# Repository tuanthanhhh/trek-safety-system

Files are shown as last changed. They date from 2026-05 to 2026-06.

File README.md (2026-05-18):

# Outdoor Safety Tracker System
> A Personal Outdoor Safety Tracker designed for trekking and remote activities, featuring fall detection, GPS tracking, environmental sensing, and LoRa-based emergency communication for real-time user monitoring.

## 📌 Overview
This project implements a handheld embedded system that enhances user safety during outdoor activities such as trekking, hiking, or exploration in remote areas.

The system continuously monitors user status and environment, detects abnormal conditions (e.g., fall or unconsciousness), and transmits alerts to a central monitoring station via LoRa communication.

## 🎯 Key Features
- Fall detection
- Lora Communication
- GPS Tracking
- Environmental Monitoring
- Digital Compass
- Emergency SOS

## 🏗️ System Architecture
🚧 Work in progress

## 🔧 Hardware Components
🚧 Work in progress
## 🧠 Software Design

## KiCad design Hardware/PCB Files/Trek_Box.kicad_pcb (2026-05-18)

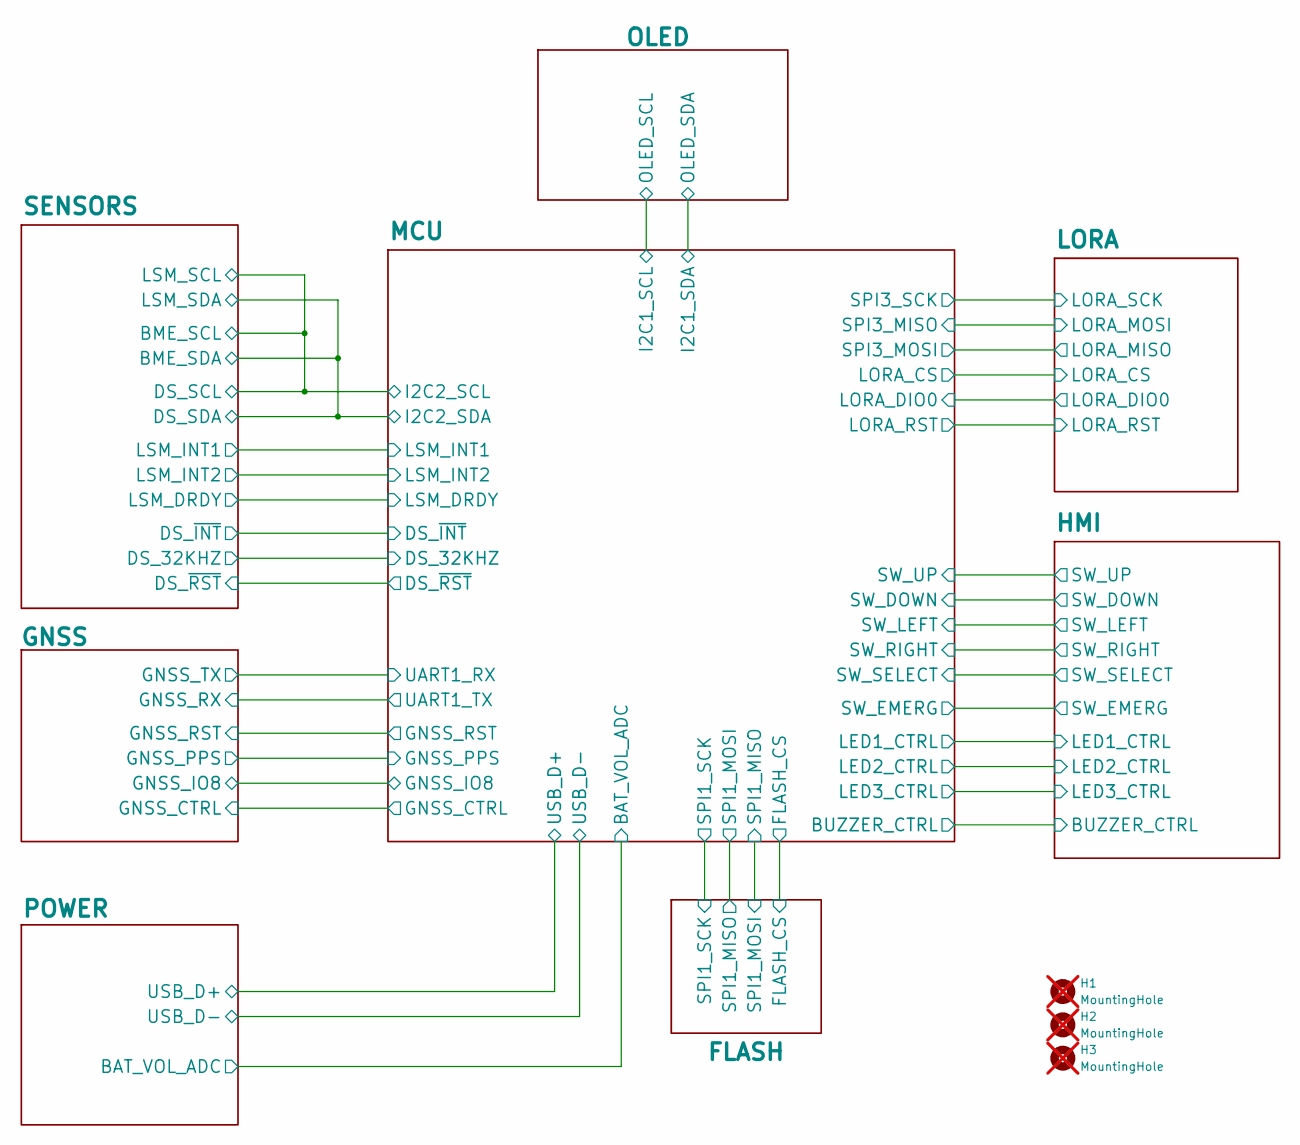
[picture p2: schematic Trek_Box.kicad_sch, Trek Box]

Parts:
H1, H2, H3: MountingHole; MountingHole_2.5mm; not fitted

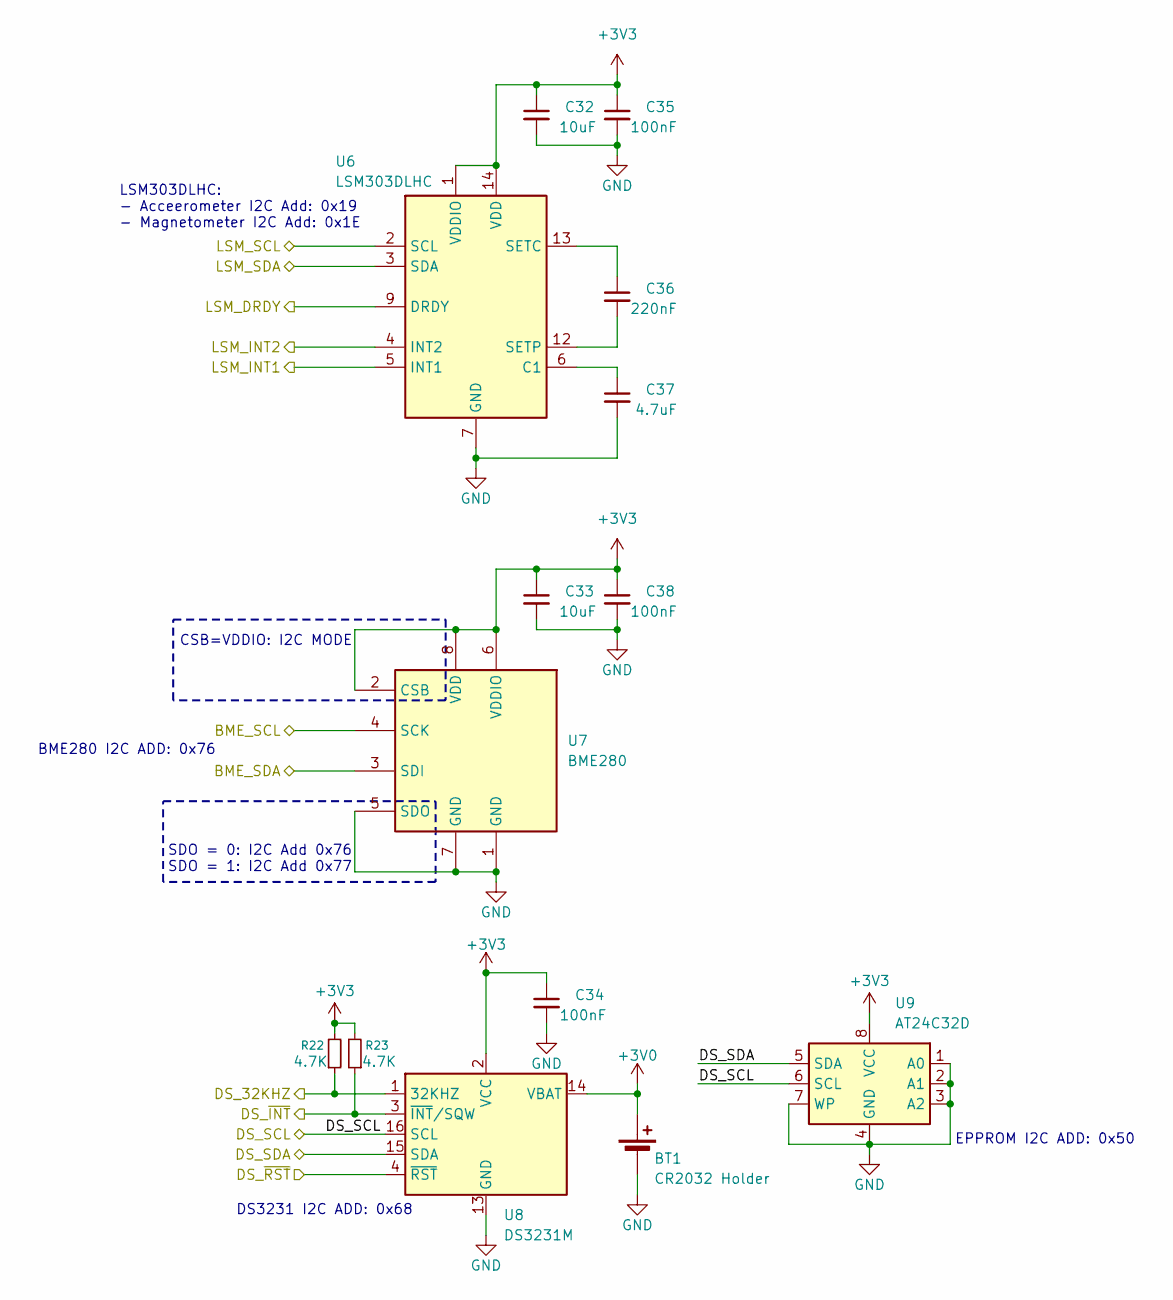
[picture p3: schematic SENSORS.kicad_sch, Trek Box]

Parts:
BT1: CR2032 Holder; BatteryHolder_Keystone_1060_1x2032
C32, C33: 10uF; C_0603_1608Metric; JLC C19702
C34, C35, C38: 100nF; C_0603_1608Metric; JLC C19702
C36: 220nF; C_0603_1608Metric; JLC C19702
C37: 4.7uF; C_0603_1608Metric; JLC C19702
R22, R23: 4.7K; R_0603_1608Metric
U6: LSM303DLHC; LGA-14_3x5mm_P0.8mm_LayoutBorder1x6y
U7: BME280; Bosch_LGA-8_2.5x2.5mm_P0.65mm_ClockwisePinNumbering
U8: DS3231M; SOIC-16W_7.5x10.3mm_P1.27mm
U9: AT24C32D; SOIC-8_3.9x4.9mm_P1.27mm

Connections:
+3V0: BT1.1 (+), U8.14 (VBAT); also elsewhere on the board
+3V3: C32.1, C33.1, C34.1, C35.1, C38.1, R22.2, R23.2, U6.1 (VDDIO), U6.14 (VDD), U7.2 (CSB), U7.6 (VDDIO), U7.8 (VDD), U8.2 (VCC), U9.8 (VCC); also elsewhere on the board
/MCU/DS_32KHZ: R22.1, U8.1 (32KHZ); also elsewhere on the board
/MCU/DS_~INT: R23.1, U8.3 (~INT/SQW); also elsewhere on the board
/MCU/DS_~RST: U8.4 (~RST); also elsewhere on the board
/MCU/I2C2_SCL: U6.2 (SCL), U7.4 (SCK), U8.16 (SCL), U9.6 (SCL); also elsewhere on the board
/MCU/I2C2_SDA: U6.3 (SDA), U7.3 (SDI), U8.15 (SDA), U9.5 (SDA); also elsewhere on the board
/MCU/LSM_DRDY: U6.9 (DRDY); also elsewhere on the board
/MCU/LSM_INT1: U6.5 (INT1); also elsewhere on the board
/MCU/LSM_INT2: U6.4 (INT2); also elsewhere on the board
GND: BT1.2 (-), C32.2, C33.2, C34.2, C35.2, C37.2, C38.2, U6.7 (GND), U6.10 (GND), U6.11 (GND), U7.1 (GND), U7.5 (SDO), U7.7 (GND), U8.5 (GND), U8.6 (GND), U8.7 (GND), U8.8 (GND), U8.9 (GND), U8.10 (GND), U8.11 (GND), U8.12 (GND), U8.13 (GND), U9.1 (A0), U9.2 (A1), U9.3 (A2), U9.4 (GND), U9.7 (WP); also elsewhere on the board
unnamed: C37.1, U6.6 (C1)
unnamed: C36.1, U6.13 (SETC)
unnamed: C36.2, U6.12 (SETP)

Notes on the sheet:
BME280 I2C ADD: 0x76
LSM303DLHC: - Acceerometer I2C Add: 0x19 - Magnetometer I2C Add: 0x1E
DS3231 I2C ADD: 0x68
SDO = 0: I2C Add 0x76 SDO = 1: I2C Add 0x77
CSB=VDDIO: I2C MODE
EPPROM I2C ADD: 0x50

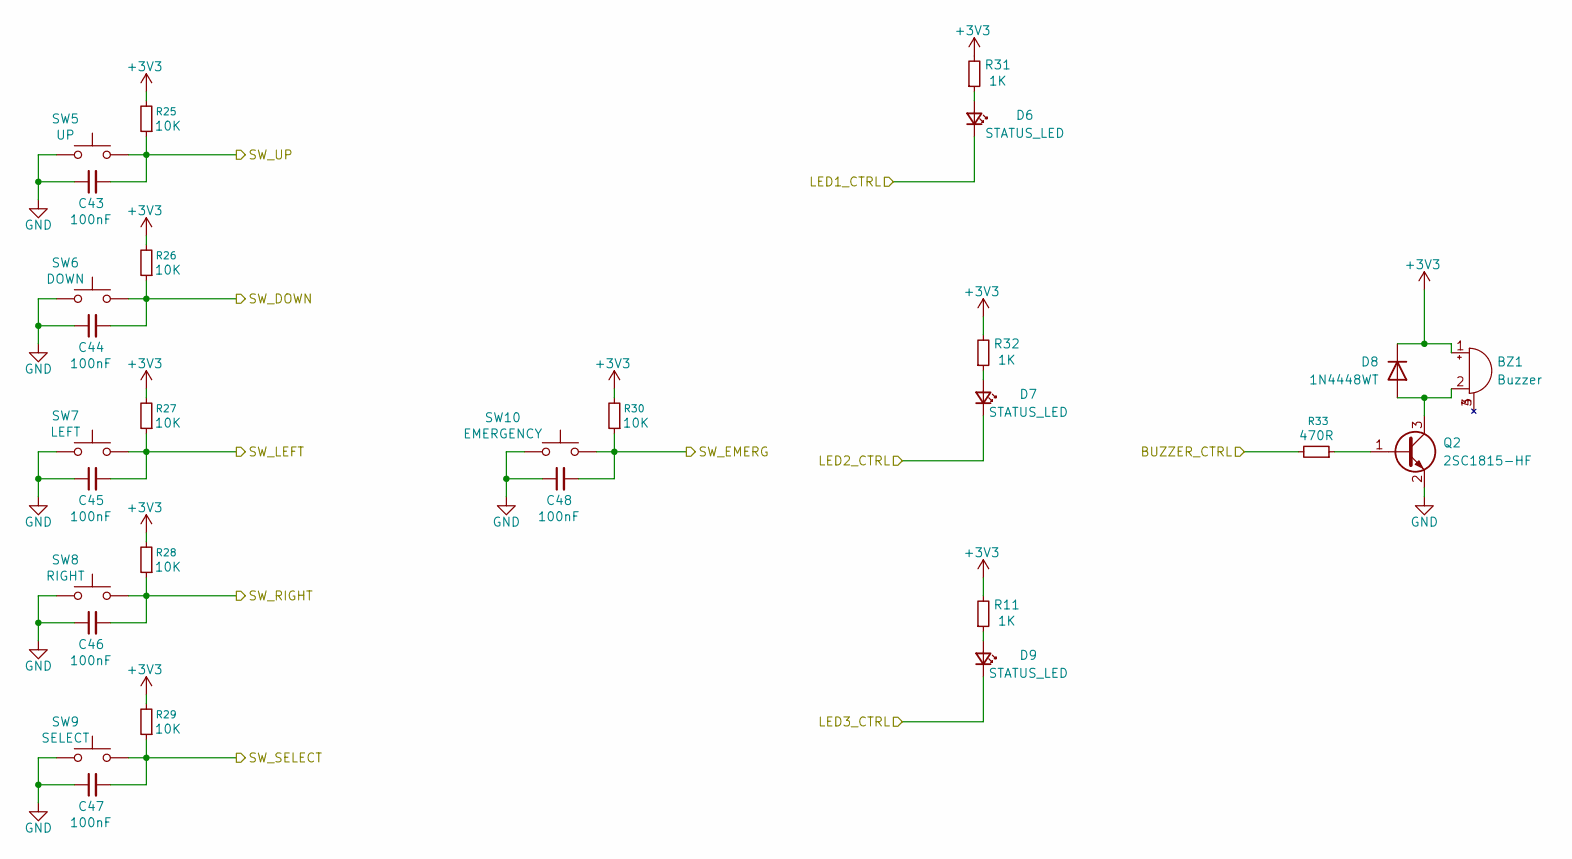
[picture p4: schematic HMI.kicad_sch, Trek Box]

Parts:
BZ1: Buzzer; Buzzer_8530
C43, C44, C45, C46, C47, C48: 100nF; C_0603_1608Metric
D6, D7, D9: STATUS_LED; LED_0603_1608Metric; JLC C2286
D8: 1N4448WT; D_SOD-523
Q2: 2SC1815-HF; SOT-23
R11, R31, R32: 1K; R_0603_1608Metric
R25, R26, R27, R28, R29, R30: 10K; R_0603_1608Metric
R33: 470R; R_0603_1608Metric
SW5: UP; SW_SPST_PTS647_Sx38
SW6: DOWN; SW_SPST_PTS647_Sx38
SW7: LEFT; SW_SPST_PTS647_Sx38
SW8: RIGHT; SW_SPST_PTS647_Sx38
SW9: SELECT; SW_SPST_PTS647_Sx38
SW10: EMERGENCY; SW_Tactile_SPST_Angled_PTS645Vx58-2LFS

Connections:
+3V3: BZ1.1 (+), D8.1 (K), R11.2, R25.2, R26.2, R27.2, R28.2, R29.2, R30.2, R31.2, R32.2; also elsewhere on the board
/HMI/BUZZER_CTRL: R33.2; also elsewhere on the board
/HMI/LED1_CTRL: D6.1 (K); also elsewhere on the board
/HMI/LED2_CTRL: D7.1 (K); also elsewhere on the board
/HMI/LED3_CTRL: D9.1 (K); also elsewhere on the board
/HMI/SW_DOWN: C44.2, R26.1, SW6.1; also elsewhere on the board
/HMI/SW_EMERG: C48.2, R30.1, SW10.1; also elsewhere on the board
/HMI/SW_LEFT: C45.2, R27.1, SW7.1; also elsewhere on the board
/HMI/SW_RIGHT: C46.2, R28.1, SW8.1; also elsewhere on the board
/HMI/SW_SELECT: C47.2, R29.1, SW9.1; also elsewhere on the board
/HMI/SW_UP: C43.2, R25.1, SW5.1; also elsewhere on the board
GND: C43.1, C44.1, C45.1, C46.1, C47.1, C48.1, Q2.2 (E), SW5.2, SW6.2, SW7.2, SW8.2, SW9.2, SW10.2; also elsewhere on the board
unnamed: BZ1.2 (-), D8.2 (A), Q2.3 (C)
unnamed: D6.2 (A), R31.1
unnamed: D7.2 (A), R32.1
unnamed: D9.2 (A), R11.1
unnamed: Q2.1 (B), R33.1

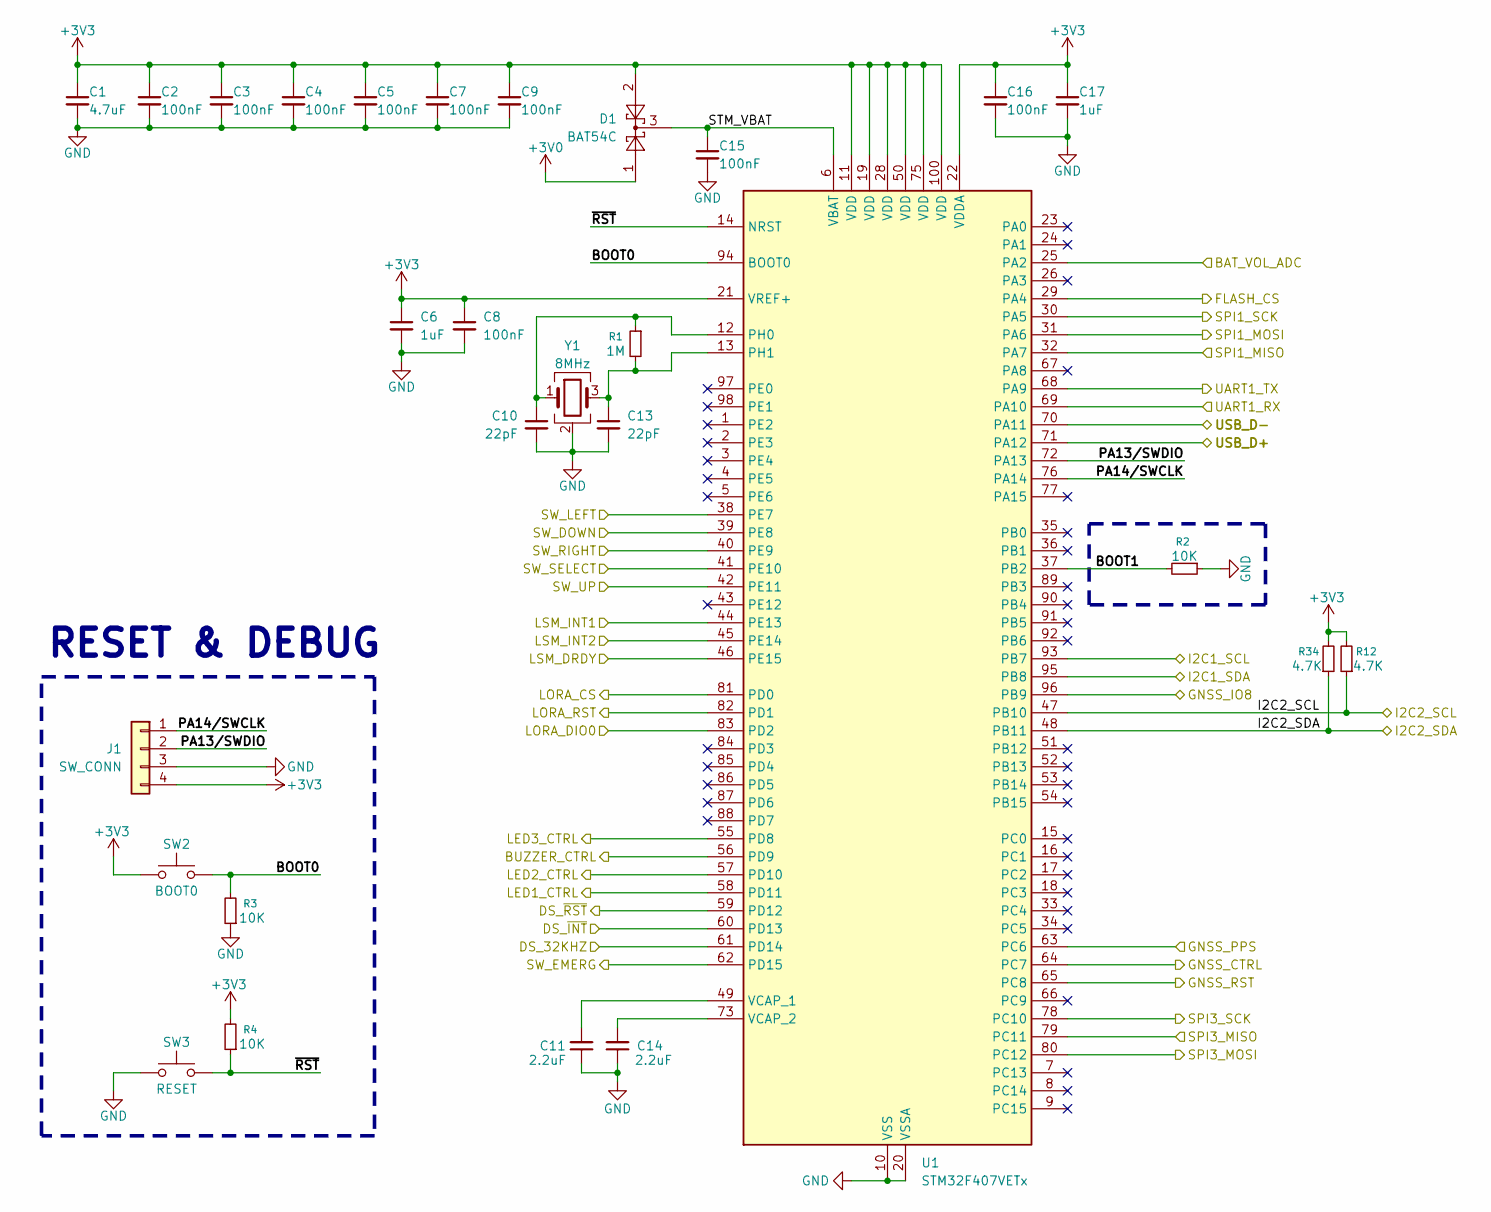
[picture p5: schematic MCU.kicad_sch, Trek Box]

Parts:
C1: 4.7uF; C_0603_1608Metric
C2, C3, C4, C5, C7, C8, C9, C15, C16: 100nF; C_0603_1608Metric
C6, C17: 1uF; C_0603_1608Metric
C10, C13: 22pF; C_0603_1608Metric
C11, C14: 2.2uF; C_0603_1608Metric
D1: BAT54C; SOT-23
J1: SW_CONN; PinHeader_1x04_P2.54mm_Vertical
R1: 1M; R_0603_1608Metric
R2, R3, R4: 10K; R_0603_1608Metric
R12, R34: 4.7K; R_0603_1608Metric
SW2: BOOT0; SW_SPST_PTS647_Sx38
SW3: RESET; SW_SPST_PTS647_Sx38
U1: STM32F407VETx; LQFP-100_14x14mm_P0.5mm
Y1: 8MHz; Crystal_SMD_3225-4Pin_3.2x2.5mm

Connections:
+3V0: D1.1; also elsewhere on the board
+3V3: C1.1, C2.1, C3.1, C4.1, C5.1, C6.1, C7.1, C8.1, C9.1, C16.1, C17.1, D1.2, J1.4, R4.2, R12.2, R34.2, SW2.2, U1.11 (VDD), U1.19 (VDD), U1.21 (VREF+), U1.22 (VDDA), U1.28 (VDD), U1.50 (VDD), U1.75 (VDD), U1.100 (VDD); also elsewhere on the board
/FLASH/FLASH_CS: U1.29 (PA4); also elsewhere on the board
/FLASH/SPI1_MISO: U1.31 (PA6); also elsewhere on the board
/FLASH/SPI1_MOSI: U1.32 (PA7); also elsewhere on the board
/FLASH/SPI1_SCK: U1.30 (PA5); also elsewhere on the board
/GNSS/GNSS_CTRL: U1.64 (PC7); also elsewhere on the board
/GNSS/GNSS_IO8: U1.96 (PB9); also elsewhere on the board
/GNSS/GNSS_PPS: U1.63 (PC6); also elsewhere on the board
/GNSS/GNSS_RST: U1.65 (PC8); also elsewhere on the board
/GNSS/GNSS_RX: U1.68 (PA9); also elsewhere on the board
/GNSS/GNSS_TX: U1.69 (PA10); also elsewhere on the board
/HMI/BUZZER_CTRL: U1.56 (PD9); also elsewhere on the board
/HMI/LED1_CTRL: U1.58 (PD11); also elsewhere on the board
/HMI/LED2_CTRL: U1.57 (PD10); also elsewhere on the board
/HMI/LED3_CTRL: U1.55 (PD8); also elsewhere on the board
/HMI/SW_DOWN: U1.39 (PE8); also elsewhere on the board
/HMI/SW_EMERG: U1.62 (PD15); also elsewhere on the board
/HMI/SW_LEFT: U1.38 (PE7); also elsewhere on the board
/HMI/SW_RIGHT: U1.40 (PE9); also elsewhere on the board
/HMI/SW_SELECT: U1.41 (PE10); also elsewhere on the board
/HMI/SW_UP: U1.42 (PE11); also elsewhere on the board
/LORA/LORA_CS: U1.81 (PD0); also elsewhere on the board
/LORA/LORA_INT: U1.83 (PD2); also elsewhere on the board
/LORA/LORA_MISO: U1.80 (PC12); also elsewhere on the board
/LORA/LORA_MOSI: U1.79 (PC11); also elsewhere on the board
/LORA/LORA_RST: U1.82 (PD1); also elsewhere on the board
/LORA/LORA_SCK: U1.78 (PC10); also elsewhere on the board
/MCU/BAT_VOL_ADC: U1.25 (PA2); also elsewhere on the board
/MCU/BOOT0: R3.2, SW2.1, U1.94 (BOOT0)
/MCU/BOOT1: R2.2, U1.37 (PB2)
/MCU/DS_32KHZ: U1.61 (PD14); also elsewhere on the board
/MCU/DS_~INT: U1.60 (PD13); also elsewhere on the board
/MCU/DS_~RST: U1.59 (PD12); also elsewhere on the board
/MCU/I2C1_SCL: U1.93 (PB7); also elsewhere on the board
/MCU/I2C1_SDA: U1.95 (PB8); also elsewhere on the board
/MCU/I2C2_SCL: R12.1, U1.47 (PB10); also elsewhere on the board
/MCU/I2C2_SDA: R34.1, U1.48 (PB11); also elsewhere on the board
/MCU/LSM_DRDY: U1.46 (PE15); also elsewhere on the board
/MCU/LSM_INT1: U1.44 (PE13); also elsewhere on the board
/MCU/LSM_INT2: U1.45 (PE14); also elsewhere on the board
/MCU/PA13/SWDIO: J1.2, U1.72 (PA13)
/MCU/PA14/SWCLK: J1.1, U1.76 (PA14)
/MCU/STM_VBAT: C15.1, D1.3, U1.6 (VBAT)
/MCU/~RST: R4.1, SW3.1, U1.14 (NRST)
/POWER/USB_D+: U1.71 (PA12); also elsewhere on the board
/POWER/USB_D-: U1.70 (PA11); also elsewhere on the board
GND: C1.2, C2.2, C3.2, C4.2, C5.2, C6.2, C7.2, C8.2, C9.2, C10.2, C11.1, C13.2, C14.1, C15.2, C16.2, C17.2, J1.3, R2.1, R3.1, SW3.2, U1.10 (VSS), U1.20 (VSSA), U1.27 (VSS), U1.74 (VSS), U1.99 (VSS), Y1.2 (G), Y1.4 (G); also elsewhere on the board
unnamed: C10.1, R1.1, U1.12 (PH0), Y1.1
unnamed: C13.1, R1.2, U1.13 (PH1), Y1.3
unnamed: C11.2, U1.49 (VCAP_1)
unnamed: C14.2, U1.73 (VCAP_2)

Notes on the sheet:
RESET & DEBUG

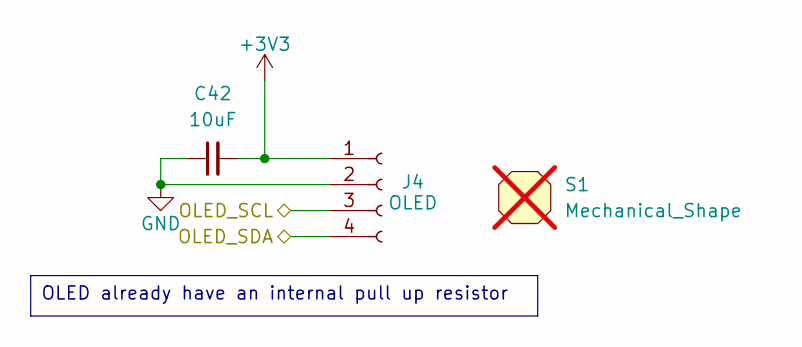
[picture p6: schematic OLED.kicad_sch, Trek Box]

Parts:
C42: 10uF; C_0603_1608Metric
J4: OLED; PinHeader_1x04_P2.54mm_Vertical
S1: Mechanical_Shape; OLED_1inch3; not fitted

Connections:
+3V3: C42.2, J4.1; also elsewhere on the board
/MCU/I2C1_SCL: J4.3; also elsewhere on the board
/MCU/I2C1_SDA: J4.4; also elsewhere on the board
GND: C42.1, J4.2; also elsewhere on the board

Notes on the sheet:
OLED already have an internal pull up resistor

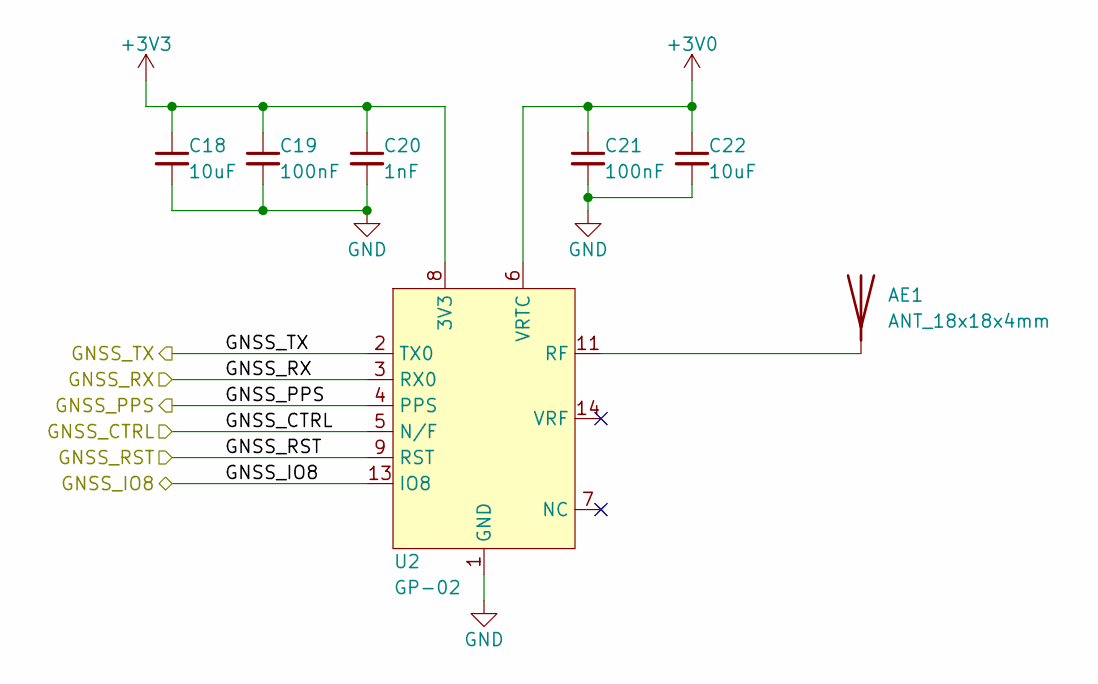
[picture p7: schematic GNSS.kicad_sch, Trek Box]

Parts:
AE1: ANT_18x18x4mm; PATH_ANT_18x18x4mm
C18, C22: 10uF; C_0603_1608Metric
C19, C21: 100nF; C_0603_1608Metric
C20: 1nF; C_0603_1608Metric
U2: GP-02; GP-02_FULL_PAD

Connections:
+3V0: C21.1, C22.1, U2.6 (VRTC); also elsewhere on the board
+3V3: C18.1, C19.1, C20.1, U2.8 (3V3); also elsewhere on the board
/GNSS/GNSS_CTRL: U2.5 (N/F); also elsewhere on the board
/GNSS/GNSS_IO8: U2.13 (IO8); also elsewhere on the board
/GNSS/GNSS_PPS: U2.4 (PPS); also elsewhere on the board
/GNSS/GNSS_RST: U2.9 (RST); also elsewhere on the board
/GNSS/GNSS_RX: U2.3 (RX0); also elsewhere on the board
/GNSS/GNSS_TX: U2.2 (TX0); also elsewhere on the board
GND: C18.2, C19.2, C20.2, C21.2, C22.2, U2.1 (GND), U2.10 (GND), U2.12 (GND); also elsewhere on the board
unnamed: AE1.1 (A_1), U2.11 (RF)

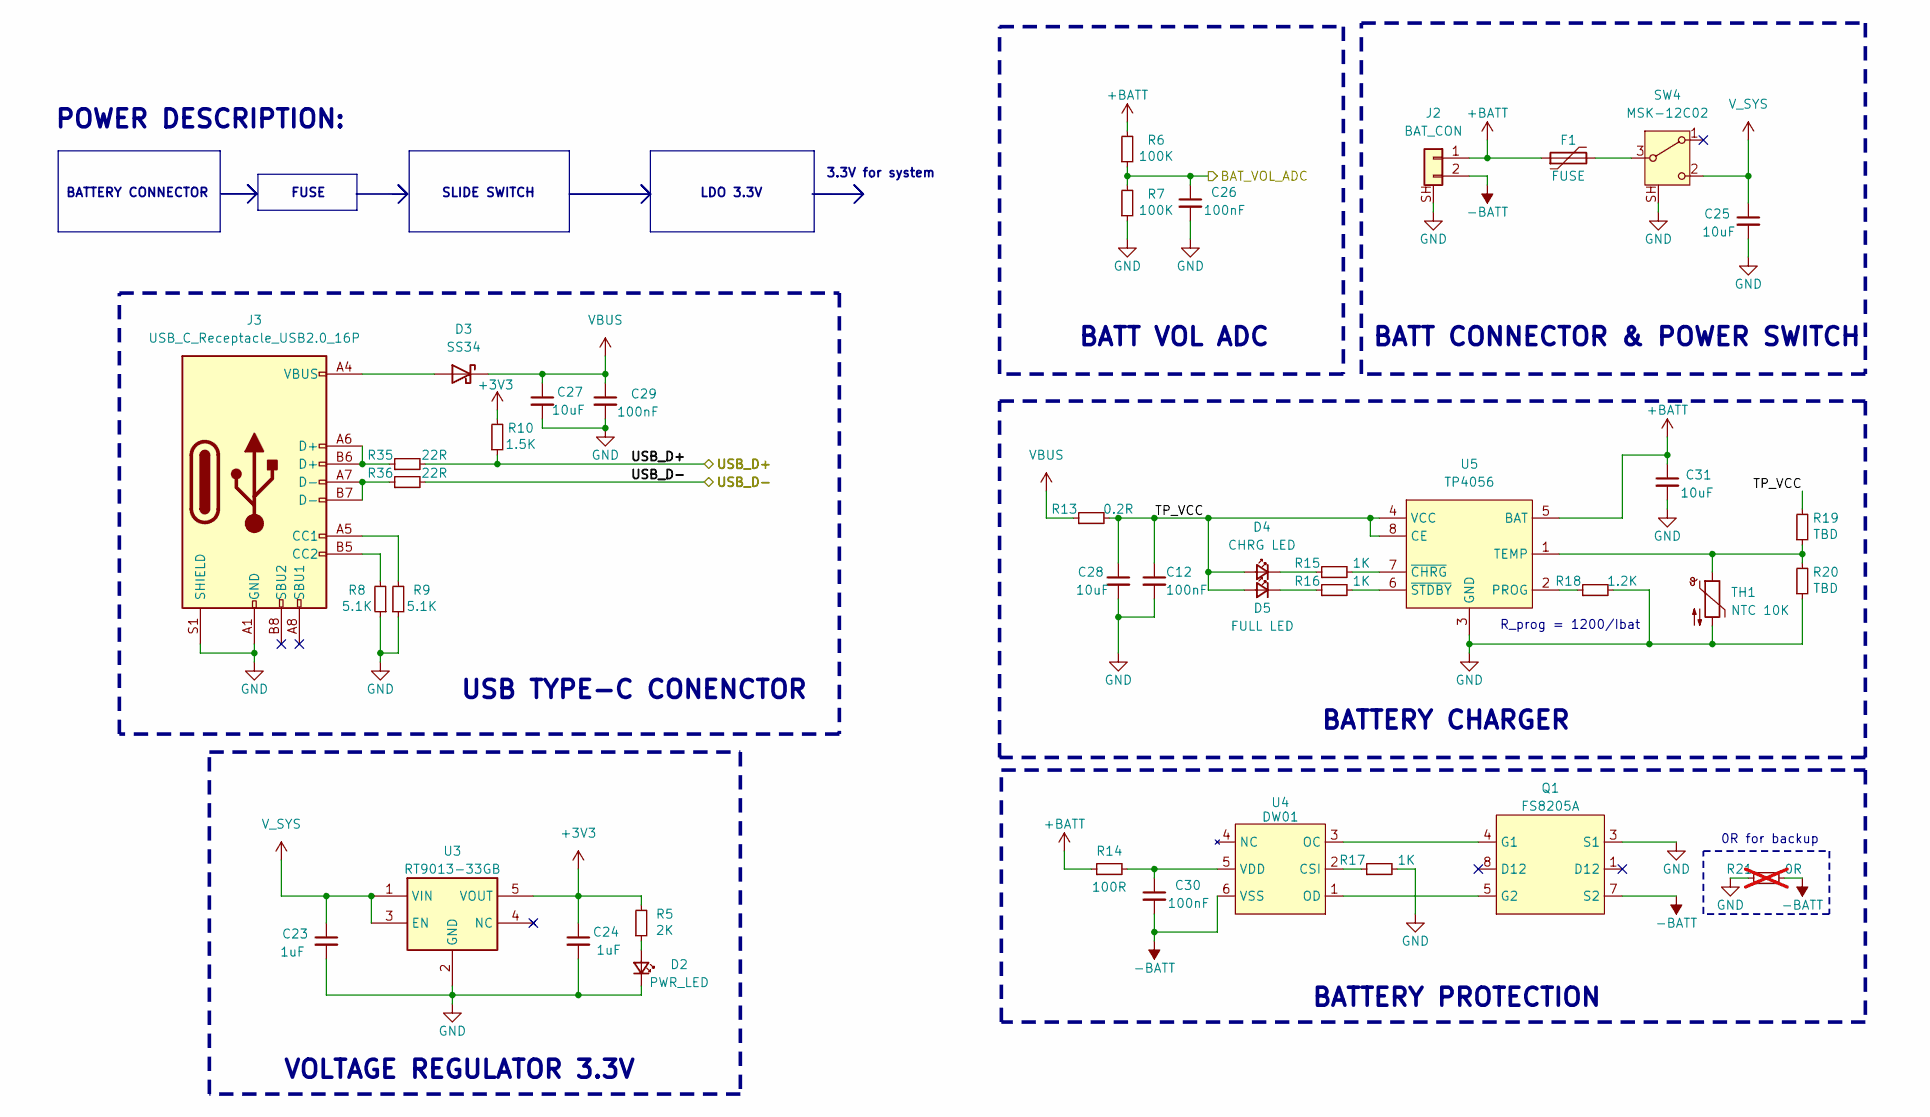
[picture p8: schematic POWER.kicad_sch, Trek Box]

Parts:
C12: 100nF; C_0603_1608Metric
C23, C24: 1uF; C_0603_1608Metric; JLC C19702
C25, C31: 10uF; C_0603_1608Metric; JLC C19702
C26, C30: 100nF; C_0603_1608Metric; JLC C1590
C27, C28: 10uF; C_0805_2012Metric
C29: 100nF; C_0603_1608Metric; JLC C19702
D2: PWR_LED; LED_0603_1608Metric; JLC C2286
D3: SS34; D_SMA
D4: CHRG LED; LED_0603_1608Metric; JLC C2286
D5: FULL LED; LED_0603_1608Metric; JLC C22371299
F1: FUSE; Fuse_0805_2012Metric; JLC C720076
J2: BAT_CON; CON_XH_254_R_SMD
J3: USB_C_Receptacle_USB2.0_16P; USB_C_Receptacle_GCT_USB4105-xx-A_16P_TopMnt_Horizontal
Q1: FS8205A; TSSOP-8_4.4x3mm_P0.65mm
R5: 2K; R_0603_1608Metric
R6, R7: 100K; R_0603_1608Metric
R8, R9: 5.1K; R_0603_1608Metric
R10: 1.5K; R_0603_1608Metric
R13: 0.2R; R_1206_3216Metric
R14: 100R; R_0603_1608Metric
R15, R16, R17: 1K; R_0603_1608Metric; JLC C22548
R18: 1.2K; R_0603_1608Metric; JLC C22765
R19, R20: TBD; R_0603_1608Metric
R21: 0R; R_0603_1608Metric; not fitted
R35, R36: 22R; R_0402_1005Metric
SW4: MSK-12C02; SW_SPDT_Shouhan_MSK12C02; JLC C963206
TH1: NTC 10K; R_0603_1608Metric
U3: RT9013-33GB; SOT-23-5
U4: DW01; SOT-23-6; JLC C917079
U5: TP4056; SOIC127P600X175-9N; JLC C725790

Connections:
+3V3: C24.1, R5.2, R10.2, U3.5 (VOUT); also elsewhere on the board
+BATT: C31.1, F1.1, J2.1, R6.2, R14.1, U5.5 (BAT)
-BATT: C30.2, J2.2, Q1.6 (S2), Q1.7 (S2), R21.2, U4.6 (VSS)
/MCU/BAT_VOL_ADC: C26.1, R6.1, R7.2; also elsewhere on the board
/POWER/TP_VCC: C12.1, C28.1, D4.2 (A), D5.2 (A), R13.2, R19.2, U5.4 (VCC), U5.8 (CE)
/POWER/USB_D+: R10.1, R35.2; also elsewhere on the board
/POWER/USB_D-: R36.2; also elsewhere on the board
GND: C12.2, C23.2, C24.2, C25.2, C26.2, C27.2, C28.2, C29.2, C31.2, D2.1 (K), J2.SH, J3.A1 (GND), J3.A12 (GND), J3.B1 (GND), J3.B12 (GND), J3.S1 (SHIELD), Q1.2 (S1), Q1.3 (S1), R7.1, R8.1, R9.1, R17.2, R18.2, R20.1, R21.1, SW4.SH, TH1.2, U3.2 (GND), U5.3 (GND), U5.9 (EPAD); also elsewhere on the board
unnamed: D2.2 (A), R5.1
unnamed: D3.2 (A), J3.A4 (VBUS), J3.A9 (VBUS), J3.B4 (VBUS), J3.B9 (VBUS)
unnamed: D4.1 (K), R15.1
unnamed: D5.1 (K), R16.1
unnamed: J3.A5 (CC1), R9.2
unnamed: J3.B5 (CC2), R8.2
unnamed: J3.A6 (D+), J3.B6 (D+), R35.1
unnamed: J3.A7 (D-), J3.B7 (D-), R36.1
unnamed: Q1.4 (G1), U4.3 (OC)
unnamed: Q1.5 (G2), U4.1 (OD)
unnamed: F1.2, SW4.3 (A)
unnamed: R17.1, U4.2 (CSI)
unnamed: C30.1, R14.2, U4.5 (VDD)
unnamed: R18.1, U5.2 (PROG)
unnamed: R19.1, R20.2, TH1.1, U5.1 (TEMP)
unnamed: R15.2, U5.7 (~CHRG)
unnamed: R16.2, U5.6 (~STDBY)
VBUS: C27.1, C29.1, D3.1 (K), R13.1
V_SYS: C23.1, C25.1, SW4.2 (C), U3.1 (VIN), U3.3 (EN)

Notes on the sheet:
VOLTAGE REGULATOR 3.3V
BATT CONNECTOR & POWER SWITCH
BATTERY PROTECTION
USB TYPE-C CONENCTOR
FUSE
0R for backup
3.3V for system
POWER DESCRIPTION:
LDO 3.3V
SLIDE SWITCH
BATTERY CONNECTOR
BATTERY CHARGER
BATT VOL ADC
R_prog = 1200/Ibat

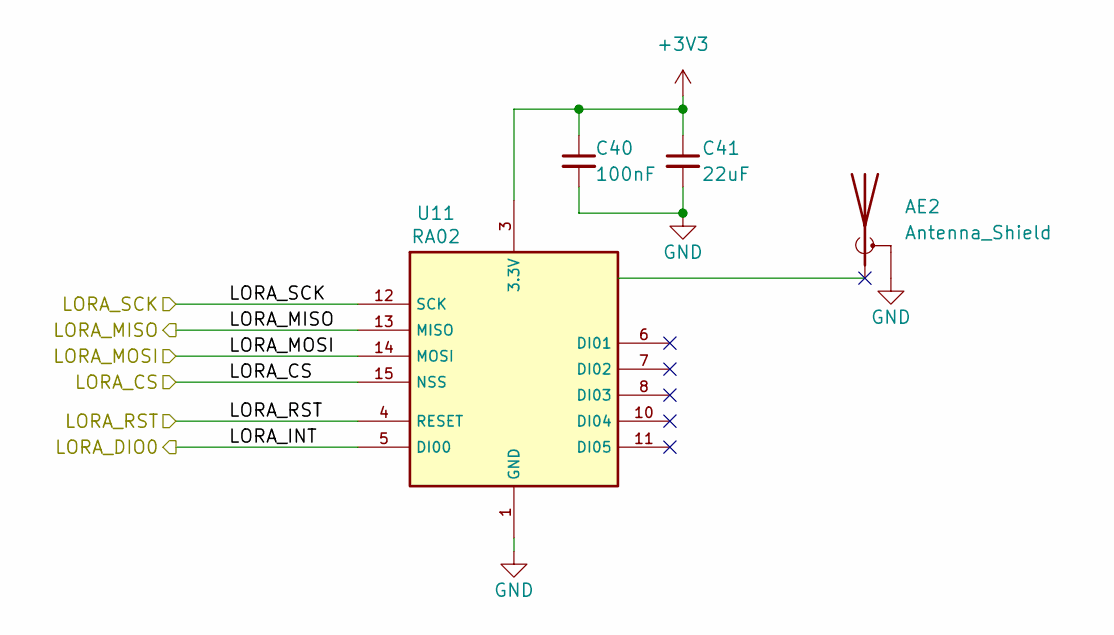
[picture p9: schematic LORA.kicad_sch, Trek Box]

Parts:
AE2: Antenna_Shield; SMA_Molex_73251-2200_Horizontal
C40: 100nF; C_0603_1608Metric
C41: 22uF; C_0805_2012Metric
U11: RA02; RA-02

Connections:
+3V3: C40.1, C41.1, U11.3 (3.3V); also elsewhere on the board
/LORA/LORA_CS: U11.15 (NSS); also elsewhere on the board
/LORA/LORA_INT: U11.5 (DI00); also elsewhere on the board
/LORA/LORA_MISO: U11.13 (MISO); also elsewhere on the board
/LORA/LORA_MOSI: U11.14 (MOSI); also elsewhere on the board
/LORA/LORA_RST: U11.4 (RESET); also elsewhere on the board
/LORA/LORA_SCK: U11.12 (SCK); also elsewhere on the board
GND: AE2.2 (Shield_2), C40.2, C41.2, U11.1 (GND), U11.2 (GND), U11.9 (GND), U11.16 (GND); also elsewhere on the board

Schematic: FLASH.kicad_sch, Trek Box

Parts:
C39: 100nF; C_0603_1608Metric
R24: 10K; R_0603_1608Metric
U10: W25Q32JVSS; SOIC-8_5.3x5.3mm_P1.27mm

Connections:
+3V3: C39.1, R24.1, U10.3 (~WP/IO_{2}), U10.7 (~HOLD/~RESET/IO_{3}), U10.8 (VCC); also elsewhere on the board
/FLASH/FLASH_CS: R24.2, U10.1 (~CS); also elsewhere on the board
/FLASH/SPI1_MISO: U10.2 (DO/IO_{1}); also elsewhere on the board
/FLASH/SPI1_MOSI: U10.5 (DI/IO_{0}); also elsewhere on the board
/FLASH/SPI1_SCK: U10.6 (CLK); also elsewhere on the board
GND: C39.2, U10.4 (GND); also elsewhere on the board

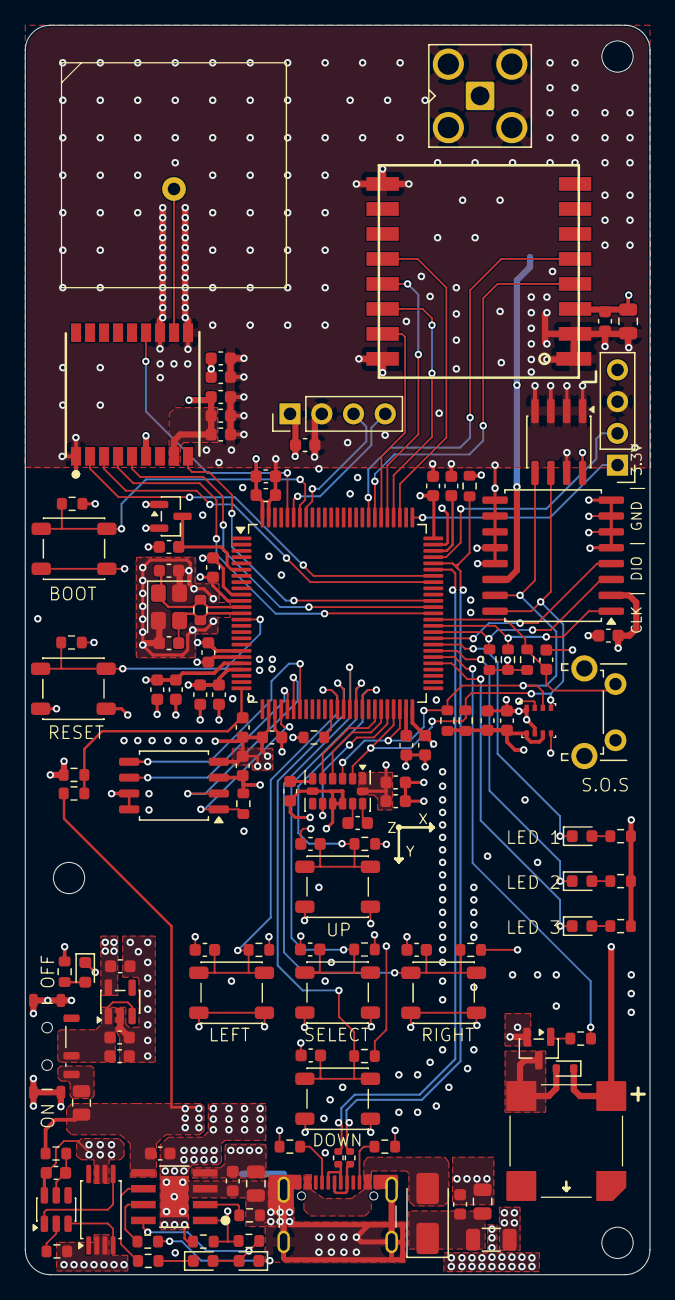
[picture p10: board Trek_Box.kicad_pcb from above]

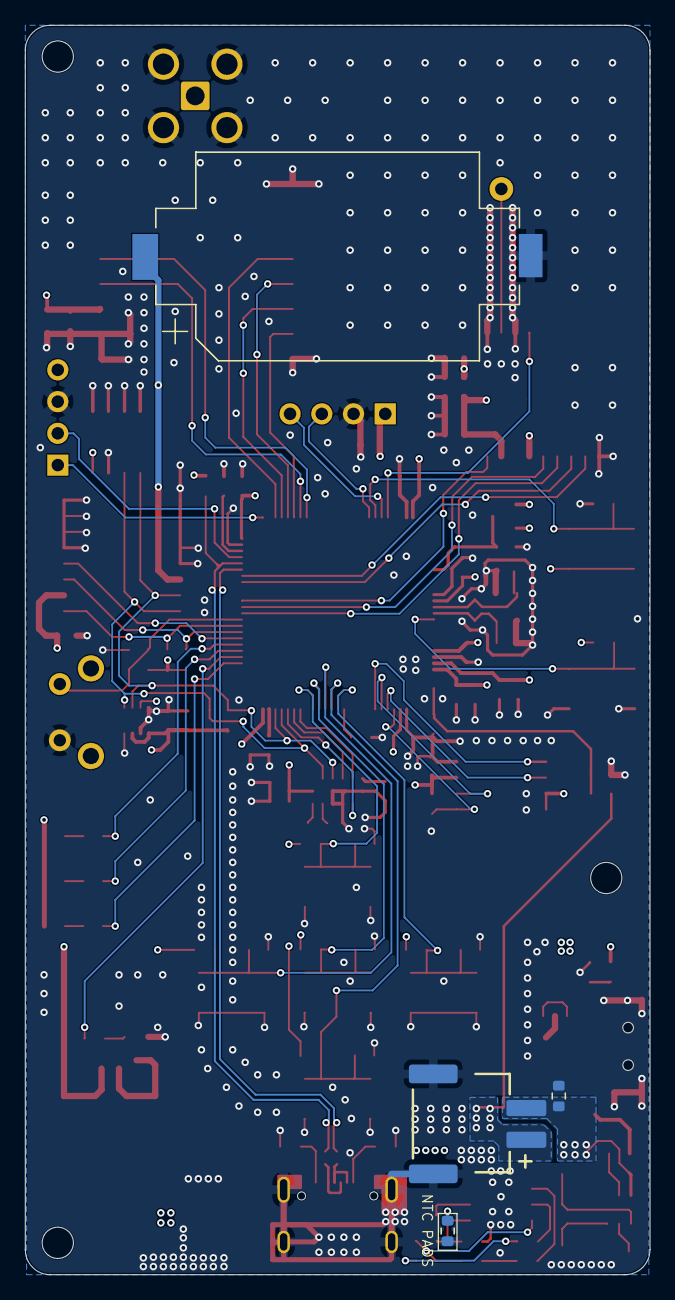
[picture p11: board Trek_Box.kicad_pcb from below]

Board: 4 copper layers, 50.0 x 100.0 mm, 130 parts (4 on the bottom side), 83 nets.

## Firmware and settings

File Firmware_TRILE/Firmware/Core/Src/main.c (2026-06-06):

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
/* Includes ------------------------------------------------------------------*/
#include "main.h"

/* USER CODE BEGIN Includes */
#include "stdio.h"
#include "fonts.h"
#include "SH1106.h"
#include "DS3231.h"
#include "lsm303dlhc.h"
#include "BME280.h"
#include "math.h"
#include "Application.h"
#include "bitmap.h"
#include "UI.h"
#include "slave_lora.h"
#include "../Function/Function_Help.h"
#include "../Function/Function_Gather.h"
/* USER CODE END Includes */

ADC_HandleTypeDef hadc1;

I2C_HandleTypeDef hi2c1;
I2C_HandleTypeDef hi2c2;

SPI_HandleTypeDef hspi3;

TIM_HandleTypeDef htim1;

UART_HandleTypeDef huart1;

void SystemClock_Config(void);
static void MX_GPIO_Init(void);
static void MX_I2C1_Init(void);
static void MX_I2C2_Init(void);
static void MX_USART1_UART_Init(void);
static void MX_TIM1_Init(void);
static void MX_ADC1_Init(void);
static void MX_SPI3_Init(void);
/* USER CODE BEGIN PFP */
void Sensor_Init(void);
/* USER CODE END PFP */

/**
  * @brief  The application entry point.
  * @retval int
  */
int main(void)
{

  /* MCU Configuration--------------------------------------------------------*/

  /* Reset of all peripherals, Initializes the Flash interface and the Systick. */
  HAL_Init();

  /* Configure the system clock */
  SystemClock_Config();

  /* Initialize all configured peripherals */
  MX_GPIO_Init();
  MX_I2C1_Init();
  MX_I2C2_Init();
  MX_USART1_UART_Init();
  MX_TIM1_Init();
  MX_ADC1_Init();
  MX_SPI3_Init();
  /* USER CODE BEGIN 2 */
  App_Trekking_Init();
  Slave_Lora_Init(&hspi3, SPI3_CS_GPIO_Port, SPI3_CS_Pin, SPI3_RST_GPIO_Port, SPI3_RST_Pin, SPI3_DIO0_GPIO_Port, SPI3_DIO0_Pin);

  SH1106_Clear();
//  DS3231_SetHour(22);
//  DS3231_SetMinute(48);
//	DS3231_SetDayOfWeek(6);
//	DS3231_SetDate(16);
//	DS3231_SetMonth(5);
//	DS3231_SetYear(2026);

  /* USER CODE END 2 */

  /* Infinite loop */
  /* USER CODE BEGIN WHILE */
  while (1)
  {
    /* USER CODE END WHILE */

    /* USER CODE BEGIN 3 */
//	  App_Weather();

//	  App_Compass();
      if (Function_Help_Is_Active())
      {
          Function_Help_Draw();
      }
      else if (Function_Gather_Is_Active())
      {
          Function_Gather_Draw();
      }
      else
	  switch(UI_state)
	  {
	  case Main_Screen:
		  App_CurrentTime();
		  Update_Main_Screen();
		  break;
	  case Menu_Screen_Compass:
		  if(UI_state_old != UI_state)
		  {
			  Menu_Compass_UI();
			  UI_state_old = UI_state;
		  }
		  break;
	  case Menu_Screen_Settings:
		  if(UI_state_old != UI_state)
		  {
			  Menu_Settings_UI();
			  UI_state_old = UI_state;
		  }
		  break;
	  case Menu_Screen_GPS:
		  if(UI_state_old != UI_state)
		  {
			  Menu_GPS_UI();
			  UI_state_old = UI_state;
		  }
		  break;
	  case Digital_Compass_Screen:
		  Compass_UI();
		  break;
	  case Digital_Compass_Calib_Screen:
		  Calib_Compass();
		  break;
	  case GPS_Screen:
		  App_GPS();
		  break;
	  case SOS_Screen:
		  if(UI_state_old != UI_state)
		  {
			  SOS_UI();
			  UI_state_old = UI_state;
			  HAL_TIM_Base_Start_IT(&htim1);
		  }

	  default:
		  UI_state_old = UI_state;
		  break;
	  }

//	  HAL_Delay(500);
	  App_Weather();
	  GPS_Process_Loop();
	  tx_lora_frame.batt = (uint8_t)battery_percent;
	  tx_lora_frame.sensor.humi = (uint8_t)BME280.Humidity;
	  tx_lora_frame.sensor.temp = (uint8_t)BME280.Temperature;
	  tx_lora_frame.gps.lat = current_gps.latitude;
	  tx_lora_frame.gps.lng = current_gps.longitude;
	  Slave_Lora_Loop();
	  HAL_ADC_Start_IT(&hadc1);
  }
  /* USER CODE END 3 */
}

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
/* USER CODE BEGIN 4 */
void HAL_TIM_PeriodElapsedCallback(TIM_HandleTypeDef *htim)
{
    if(htim->Instance == TIM1)
    {
    	if(tx_lora_frame.cmd_lora == CMD_LORA_SOS)
    	{
    		HAL_GPIO_TogglePin(BUZZER_CTR_GPIO_Port, BUZZER_CTR_Pin);
    	}
    	else
    	{
    		HAL_GPIO_WritePin(BUZZER_CTR_GPIO_Port, BUZZER_CTR_Pin, 0);
    	}
    }
}

uint16_t u16_ADCVal;
float Voltage;
void HAL_ADC_ConvCpltCallback(ADC_HandleTypeDef *hadc)
{
	if(hadc->Instance == ADC1)
	{
		u16_ADCVal = HAL_ADC_GetValue(&hadc1);
		Voltage = (float)u16_ADCVal/4095*3.3*2;
	}

}
/* USER CODE END 4 */
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


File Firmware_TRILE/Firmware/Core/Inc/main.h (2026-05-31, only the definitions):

#define SW_LEFT_Pin GPIO_PIN_7
#define SW_LEFT_GPIO_Port GPIOE
#define SW_LEFT_EXTI_IRQn EXTI9_5_IRQn
#define SW_DOWN_Pin GPIO_PIN_8
#define SW_DOWN_GPIO_Port GPIOE
#define SW_DOWN_EXTI_IRQn EXTI9_5_IRQn
#define SW_RIGHT_Pin GPIO_PIN_9
#define SW_RIGHT_GPIO_Port GPIOE
#define SW_RIGHT_EXTI_IRQn EXTI9_5_IRQn
#define SW_SELECT_Pin GPIO_PIN_10
#define SW_SELECT_GPIO_Port GPIOE
#define SW_SELECT_EXTI_IRQn EXTI15_10_IRQn
#define SW_UP_Pin GPIO_PIN_11
#define SW_UP_GPIO_Port GPIOE
#define SW_UP_EXTI_IRQn EXTI15_10_IRQn
#define LSM_INT1_Pin GPIO_PIN_13
#define LSM_INT1_GPIO_Port GPIOE
#define LSM_INT1_EXTI_IRQn EXTI15_10_IRQn
#define LSM_INT2_Pin GPIO_PIN_14
#define LSM_INT2_GPIO_Port GPIOE
#define LSM_INT2_EXTI_IRQn EXTI15_10_IRQn
#define LED_03_Pin GPIO_PIN_8
#define LED_03_GPIO_Port GPIOD
#define BUZZER_CTR_Pin GPIO_PIN_9
#define BUZZER_CTR_GPIO_Port GPIOD
#define LED_02_Pin GPIO_PIN_10
#define LED_02_GPIO_Port GPIOD
#define LED_01_Pin GPIO_PIN_11
#define LED_01_GPIO_Port GPIOD
#define SW_SOS_Pin GPIO_PIN_15
#define SW_SOS_GPIO_Port GPIOD
#define SW_SOS_EXTI_IRQn EXTI15_10_IRQn
#define SPI3_CS_Pin GPIO_PIN_0
#define SPI3_CS_GPIO_Port GPIOD
#define SPI3_RST_Pin GPIO_PIN_1
#define SPI3_RST_GPIO_Port GPIOD
#define SPI3_DIO0_Pin GPIO_PIN_2
#define SPI3_DIO0_GPIO_Port GPIOD
#define SPI3_DIO0_EXTI_IRQn EXTI2_IRQn

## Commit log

2026-05-03 init Trekking Safety Device Project
2026-05-07 Create Hardware folder and update PCB Files
    [FLASH.kicad_sch, GNSS.kicad_sch, HMI.kicad_sch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]
2026-05-18 Add STM32F407_BASE to Firmware_TRILE folder
2026-05-18 Xoa 3 thu muc STM32 du thua khoi nhanh main
2026-05-30 fix digital compass and current time function
    [Application.c, Trekking_Slave.ioc, UI.c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]
2026-06-06 Update Firmware_TRILE from local workspace
    [[BTL_TKHTN] FRAME_CUSTOM.xlsx]

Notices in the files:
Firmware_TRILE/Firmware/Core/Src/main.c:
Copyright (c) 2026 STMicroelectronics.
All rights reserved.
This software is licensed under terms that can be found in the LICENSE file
